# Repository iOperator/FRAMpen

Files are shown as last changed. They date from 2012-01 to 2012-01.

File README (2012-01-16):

FRAMpen
Max Gröning
Thomas Bendel
2011, 2012

A project for the MSP430 FRAM challenge for TI Freising interns.

http://processors.wiki.ti.com/index.php/FRAMpen

Files & folders:

doc         Documentation.
firmware    The software for the MSP430FR5739.
pcb         The pcb files. (EAGLE 6)
software    Python script.
README      This file.

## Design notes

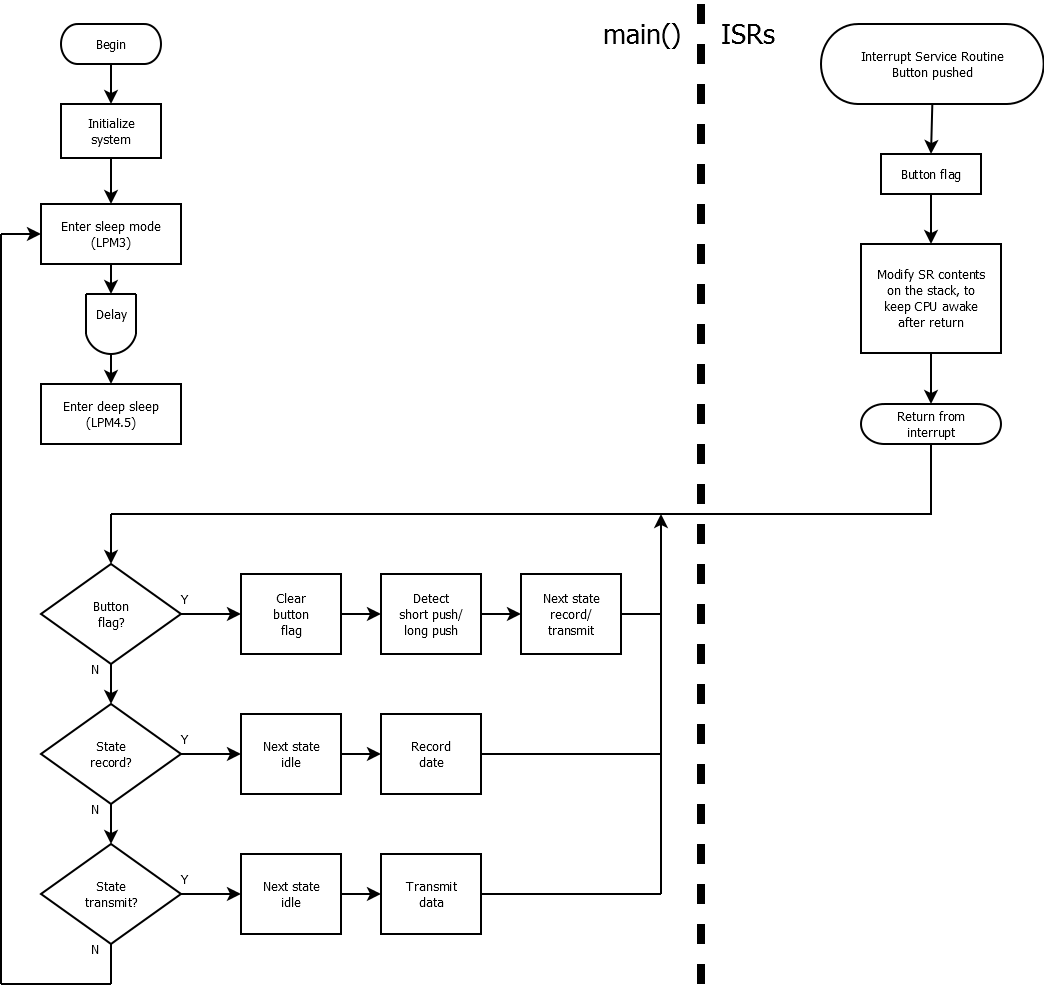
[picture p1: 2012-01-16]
doc/flow.png

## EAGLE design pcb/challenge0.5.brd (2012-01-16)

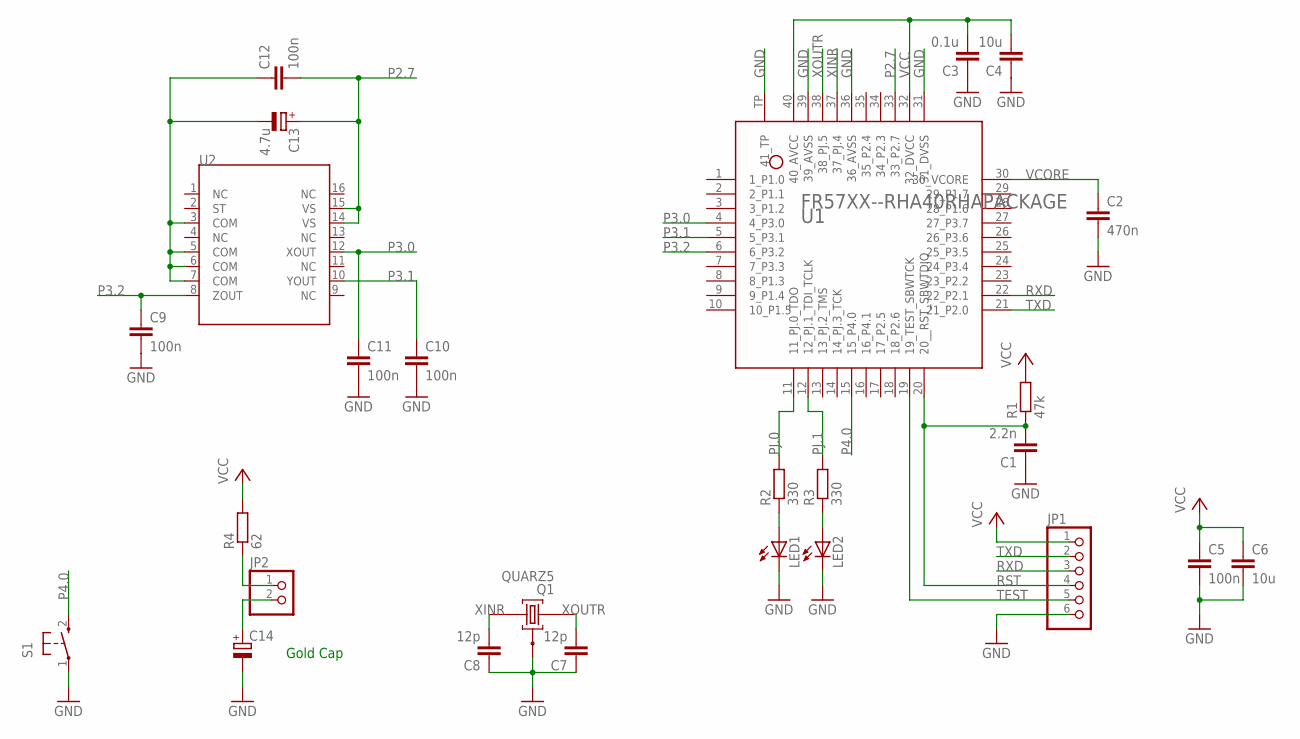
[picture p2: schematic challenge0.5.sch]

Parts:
C1: 2.2n; C0805
C2: 470n; C0805
C3: 0.1u; C0805
C4, C6: 10u; C0805
C5, C9, C10, C11, C12: 100n; C0805
C7, C8: 12p; C0805
C13: 4.7u; SMC_A
C14: CPOL-EUE10-20; EB20D
JP1: PINHD-1X6/90; 1X06/90
JP2: PINHD-1X2/90; 1X02/90
LED1, LED2: LEDCHIP-LED0805; CHIP-LED0805
Q1: QUARZ5
R1: 47k; M0805
R2, R3: 330; M0805
R4: 62; R1206
S1: PB; PBTH
U1: FR57XX--RHA40RHAPACKAGE; RHA40
U2: ADXL330; RSA16

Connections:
GND: C1.1, C2.2, C3.1, C4.1, C5.2, C6.2, C7.1, C8.1, C9.2, C10.2, C11.2, C14.-, JP1.6, LED1.C, LED2.C, Q1.GND@0 (0), S1.1, U1.31 (31_DVSS), U1.36 (36_AVSS), U1.39 (39_AVSS), U1.TP (41_TP)
GOLDCAP+1: JP2.1, R4.1
GOLDCAP+2: C14.+, JP2.2
unnamed: C12.1, C13.-, U2.3 (COM), U2.5 (COM), U2.6 (COM), U2.7 (COM)
unnamed: LED1.A, R2.1
unnamed: LED2.A, R3.1
P2.7: C12.2, C13.+, U1.33 (33_P2.7), U2.14 (VS), U2.15 (VS)
P3.0: C11.1, U1.4 (4_P3.0), U2.12 (XOUT)
P3.1: C10.1, U1.5 (5_P3.1), U2.10 (YOUT)
P3.2: C9.1, U1.6 (6_P3.2), U2.8 (ZOUT)
P4.0: S1.2 (S), U1.15 (15_P4.0)
PJ.0: R2.2, U1.11 (11_PJ.0_TDO)
PJ.1: R3.2, U1.12 (12_PJ.1_TDI_TCLK)
RST: C1.2, JP1.4, R1.1, U1.20 (20__RST_SBWTDIO)
RXD: JP1.3, U1.22 (22_P2.1)
TEST: JP1.5, U1.19 (19_TEST_SBWTCK)
TXD: JP1.2, U1.21 (21_P2.0)
VCC: C3.2, C4.2, C5.1, C6.1, JP1.1, R1.2, R4.2, U1.32 (32_DVCC), U1.40 (40_AVCC)
VCORE: C2.1, U1.30 (30_VCORE)
XINR: C8.2, Q1.1, U1.37 (37_PJ.4)
XOUTR: C7.2, Q1.2, U1.38 (38_PJ.5)

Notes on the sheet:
Gold Cap

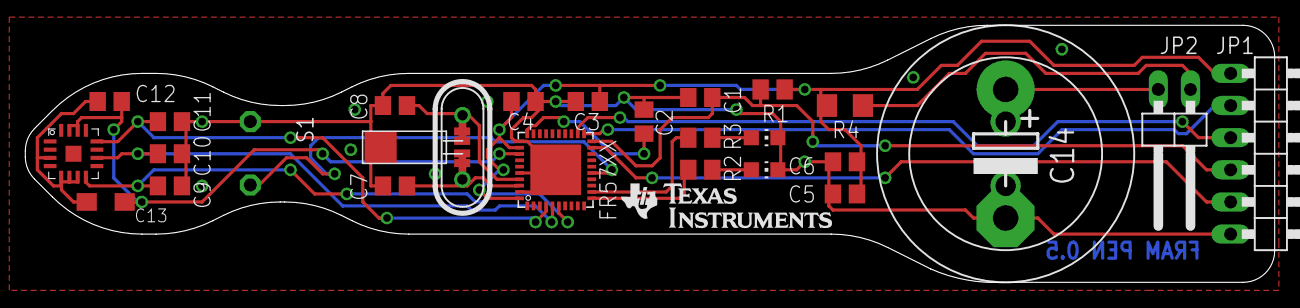
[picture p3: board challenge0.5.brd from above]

Board: 2 copper layers, 98.7 x 20.3 mm, 27 parts (0 on the bottom side), 21 nets.

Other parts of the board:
U$1: LOGO16_TPLACE

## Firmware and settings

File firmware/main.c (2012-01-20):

/*
 * main.c
 *
 *     Project: FRAMpen
 *  Created on: 14.01.2012
 *      Author: Max Groening
 *              Thomas Bendel
 */

#include "msp430fr5739.h"
#include "FRAMpen.h"
#include "init.h"
#include "vectors.h"
#include "subroutines.h"


void main(void) {

	init_system();

	volatile enum states state;
	state = IDLE;
	volatile enum button_states button_state;
	button_state = NO_PUSH;

	__enable_interrupt();

	while(1) {

		/* Check push button */
		if (button_flag == 1) {
			button_flag = 0;

			// Check push button
			unsigned int push_cnt = 0;
			button_state = NO_PUSH;
			__delay_cycles(200000);  // Wait 25 msec to debounce
			__delay_cycles(200000);  // Wait 25 msec to debounce
			while (!(P4IN & BIT0)) {  // Button pushed
				__delay_cycles(8000);  // Wait 1 msec
				push_cnt++;

				if (push_cnt > TIME_SHORT_PUSH) {  // Push button was pushed a short time
					button_state = SHORT_PUSH;
					LED1_on();
				}
				if (push_cnt > TIME_LONG_PUSH) {  // Push button was pushed a long time
					button_state = LONG_PUSH;
					LED2_on();
				}
			}
			LED1_off();
			LED2_off();
			__delay_cycles(400000);  // Wait 50 msec to debounce
			__delay_cycles(400000);  // Wait 50 msec to debounce
		}


		/* Check states */
		switch (state) {
			case IDLE:
//				toggle_led(LED1_PIN, TIME_3SEC);
				switch (button_state) {
					case LONG_PUSH:
						state = TRANSMIT;
						wdt_disable();
						LED1_off();
						toggle_led(LED2_PIN, TIME_05SEC);
						transmit_data();
						break;
					case SHORT_PUSH:
						state = RECORD;
						wdt_disable();
						LED2_off();
						toggle_led(LED1_PIN, TIME_1SEC);
						record_data();
						break;
					default:
						break;
				}
				break;

			case RECORD:
				switch (button_state) {
					case LONG_PUSH:  // Delete data
						delete_data();
						state = IDLE;
						break;
					case SHORT_PUSH:  // Stop recording
						// Recording stop from inside recorde()
						state = IDLE;
						break;
					default:
						break;
				}
//				state = IDLE;
				break;
			case TRANSMIT:
				switch (button_state) {
					case LONG_PUSH:
						break;
					case SHORT_PUSH:
						break;
					default:
						break;
				}
				state = IDLE;
				break;
			default:
				break;
		}

		//button_state = NO_PUSH;
		PAIE |= BIT0;  // Enable interrupt for push button

		if (state == IDLE) {
			toggle_led(LED1_PIN, TIME_3SEC);
			wdt_enable();  // Activate auto-deep-sleep-watchdog
			LPM3;
			_nop();
		}

	}

}

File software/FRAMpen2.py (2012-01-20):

#!/usr/bin/env python

"""FRAMpen.py: Reads and converts data from the FRAMpen.
http://processors.wiki.ti.com/index.php/FRAMpen
"""

__author__ = "Max Groening, Thomas Bendel"

#################
# Configuration #
#################

MAX_BYTES = 6666 #7164  # Maximum number of bytes to read
BAUDRATE = 9600
PORT = 2  # Windows ports start from '0'(=COM1), Linux: e.g. '/dev/ttyS1'
TIMEOUT = 30  # Timeout in seconds

DATA_RAW_FILENAME = 'raw.dat'
DATA_ACC_FILENAME = 'acc.dat'
DATA_VEL_FILENAME = 'vel.dat'
DATA_POS_FILENAME = 'pos.dat'
DATA_POS_ROT_FILENAME = 'pos_rot.dat'

DEBUG = False

AVERAGES_X = 30  # Number of samples for moving average
AVERAGES_Y = 30  #
AVERAGES_Z = 30  #

DECAY_VALUE_X = 0.00  # Intensity of decay
DECAY_VALUE_Y = 0.00  #
DECAY_VALUE_Z = 0.00  #

DISCRIMINATOR_X = 05.0  # Acceleration below the value
DISCRIMINATOR_Y = 05.0  # will be disregarded
DISCRIMINATOR_Z = 05.0  #

ZERO_X = 25  # Zero the velocity auf n sample with no acceleration
ZERO_Y = 25  #
ZERO_Z = 25  #

ROTATE = 0  # Rotate the x-, y-coordinates afterwards

##############################################
# No configuration needed beyond this point. #
##############################################

import serial  # PySerial
from math import cos, sin, pi  # Cosinus, sinus and PI for rotation
from test import *  # Test samples

### Get the data via serial connection #######################################

ser = serial.Serial()  # Open serial connection
ser.bautrate = BAUDRATE
ser.port = PORT
ser.timeout = TIMEOUT

print(ser)

ser.open()

if ser.isOpen():
    print("\nStart transmission now!\n")
else:
    print("\nCannot open port!\n")
    exit()


raw_data = ser.read(MAX_BYTES)
# raw_data = ['0']  # Disable receive for testing
ser.close()

# Convert byte (char) into decimal value
data_8 = []
for entry in raw_data:
    data_8.append(ord(entry))

# Join to (decimal) 'bytes' back into one word
# Shift 'high byte' back by multiplying with 8
data_16 = []
for high_byte, low_byte in zip(data_8[0::2], data_8[1::2]):
    data_16.append(high_byte * 256 + low_byte)

if DEBUG:
    print(data_8)
    print(data_16)

# i = 0
# while (i < len(data_8)):
#     # Shift 'high byte' back by multiply with 8
#     data_16.append(data_8[i] * 256 + data_8[i+1])
#     i += 2

# Separate data by X, Y, and Z coordinate
data_x = []
data_y = []
data_z = []

for i in range(len(data_16[0::3])):
    data_x.append(data_16[0::3][i])
    data_y.append(data_16[1::3][i])
    data_z.append(data_16[2::3][i])

if DEBUG:
    print(data_x)
    print(data_y)
    print(data_z)

# # Load test samples
# data_x = sample3_raw_x
# data_y = sample3_raw_y
# data_z = sample3_raw_z

# Output raw data
data_handle = open(DATA_RAW_FILENAME, 'w')

for i in range(len(data_x)):
    data_handle.write(str(data_x[i]) + ' ' +
                      str(data_y[i]) + ' ' +
                      str(data_z[i]) + '\n')

data_handle.close()


### Integrate acceleration ###################################################

acc_x = []  # Stores acceleration data without offset
acc_y = []  #
acc_z = []  #

# Moving averages
average_values_x = [data_x[0]] * AVERAGES_X
average_values_y = [data_y[0]] * AVERAGES_Y
average_values_z = [data_z[0]] * AVERAGES_Z

# Decay values
decay_x = 0.0
decay_y = 0.0
decay_z = 0.0

vel_x = [0] * len(data_x)  # Stores velocity data
vel_y = [0] * len(data_y)  #
vel_z = [0] * len(data_z)  #

pos_x = [0] * len(vel_x)  # Stores positional (distance) data
pos_y = [0] * len(vel_y)  #
pos_z = [0] * len(vel_z)  #

zero_counter_x = 0  # How many sequential acceleration samples are zero
zero_counter_y = 0  #
zero_counter_z = 0  #

# File handels
data_acc_handle = open(DATA_ACC_FILENAME, 'w')
data_vel_handle = open(DATA_VEL_FILENAME, 'w')
data_pos_handle = open(DATA_POS_FILENAME, 'w')


for i in range(len(data_x)):
    # Remove offset

    # right ship 'average_values', insert current sample at first position
    average_values_x = [data_x[i]] + average_values_x[:-1]
    average_values_y = [data_y[i]] + average_values_y[:-1]
    average_values_z = [data_z[i]] + average_values_z[:-1]

    tmp_x = data_x[i] - sum(average_values_x) / float(AVERAGES_X)
    tmp_y = data_y[i] - sum(average_values_y) / float(AVERAGES_Y)
    tmp_z = data_z[i] - sum(average_values_z) / float(AVERAGES_Z)

    # Filter small values (discriminator)
    if (abs(tmp_x) > DISCRIMINATOR_X):
        acc_x.append(data_x[i] - sum(average_values_x) / float(AVERAGES_X) - decay_x)
    else:
        acc_x.append(0)

    if (abs(tmp_y) > DISCRIMINATOR_Y):
        acc_y.append(data_y[i] - sum(average_values_y) / float(AVERAGES_Y) - decay_y)
    else:
        acc_y.append(0)

    if (abs(tmp_z) > DISCRIMINATOR_Z):
        acc_z.append(data_z[i] - sum(average_values_z) / float(AVERAGES_Z) - decay_z)
    else:
        acc_z.append(0)

    # Count how many sequential samples are zero
    if (acc_x[i] == 0):
        zero_counter_x += 1
    else:
        zero_counter_x = 0

    if (acc_y[i] == 0):
        zero_counter_y += 1
    else:
        zero_counter_y = 0

    if (acc_z[i] == 0):
        zero_counter_z += 1
    else:
        zero_counter_z = 0

    if DEBUG:
	print(acc_x)
	print(acc_y)
	print(acc_z)

    # Output acceleration data
    data_acc_handle.write(str(acc_x[i]) + ' ' +
                          str(acc_y[i]) + ' ' +
                          str(acc_z[i]) + '\n')

    # Integrate acceleration into velocity
    # vel_x[i] = vel_x[i-1] - acc_x[i]
    # vel_y[i] = vel_y[i-1] - acc_y[i]
    # vel_z[i] = vel_z[i-1] - acc_z[i]
    if (zero_counter_x >= ZERO_X):
        vel_x[i] = 0
        vel_x[i-1] = 0
    else:
        vel_x[i] = vel_x[i-1] + acc_x[i-1] + ((acc_x[i] - acc_x[i-1]) / 2)

    if (zero_counter_y >= ZERO_Y):
        vel_y[i] = 0
        vel_y[i-1] = 0
    else:
        vel_y[i] = vel_y[i-1] + acc_y[i-1] + ((acc_y[i] - acc_y[i-1]) / 2)

    if (zero_counter_z >= ZERO_Z):
        vel_z[i] = 0
        vel_z[i-1] = 0
    else:
        vel_z[i] = vel_z[i-1] + acc_z[i-1] + ((acc_z[i] - acc_z[i-1]) / 2)

    if DEBUG:
	print(vel_x)
	print(vel_y)
	print(vel_z)

    # Output velocity data
    data_vel_handle.write(str(vel_x[i]) + ' ' +
			  str(vel_y[i]) + ' ' +
			  str(vel_z[i]) + '\n')

    # Decay
    if (vel_x[i] > 0):
        decay_x -= DECAY_VALUE_X
    else:
        decay_x += DECAY_VALUE_X

    if (vel_y[i] > 0):
        decay_y -= DECAY_VALUE_Y
    else:
        decay_y += DECAY_VALUE_Y

    if (vel_z[i] > 0):
        decay_z -= DECAY_VALUE_Z
    else:
        decay_z += DECAY_VALUE_Z


    # Integrate velocity into distance
    # pos_x[i] = pos_x[i-1] - vel_x[i]
    # pos_y[i] = pos_y[i-1] - vel_y[i]
    # pos_z[i] = pos_z[i-1] - vel_z[i]
    pos_x[i] = pos_x[i-1] + vel_x[i-1] + ((vel_x[i] - vel_x[i-1]) / 2)
    pos_y[i] = pos_y[i-1] + vel_y[i-1] + ((vel_y[i] - vel_y[i-1]) / 2)
    pos_z[i] = pos_z[i-1] + vel_z[i-1] + ((vel_z[i] - vel_z[i-1]) / 2)

    if DEBUG:
	print(pos_x)
	print(pos_y)
	print(pos_z)
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

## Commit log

2012-01-17 firmware: Improved usability (button)
2012-01-20 Software: FRAMpen2.py - Different approach to process the coordinates test.py - Some sample to speed up development
2012-01-20 Firmware: LED bug fixed
    [main.c]
